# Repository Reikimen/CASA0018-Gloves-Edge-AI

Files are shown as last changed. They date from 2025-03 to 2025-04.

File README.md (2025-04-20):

---
typora-root-url: ./
---

# CASA0018-Gloves-Edge-AI

# Sign Language Recognition Glove

This project implements a wearable device that translates sign language gestures into text using flex sensors, an IMU, and edge ML inference.

## Project Overview

The Sign Language Recognition Glove aims to develop a wearable device that translates sign language by recognizing hand positions in real-time. This device uses flex sensors to detect finger bending and an IMU to capture hand orientation, enabling it to recognize specific sign language gestures. The system processes this data using a machine learning model deployed directly on an Arduino microcontroller, providing immediate feedback through an LCD display.

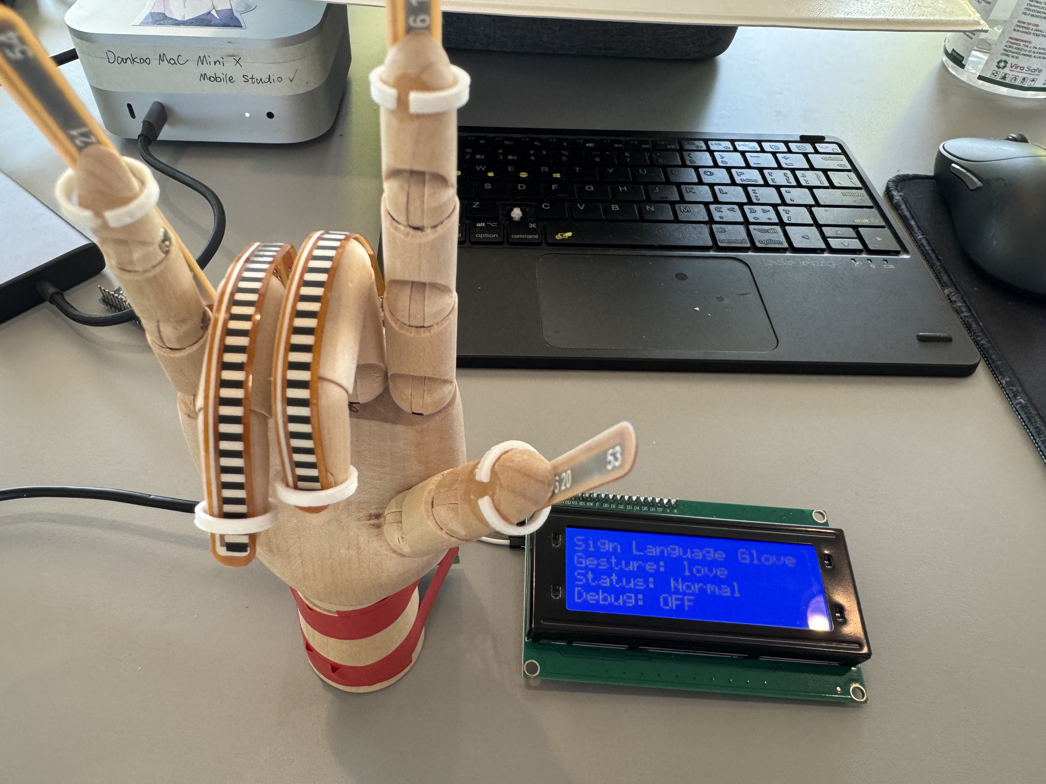
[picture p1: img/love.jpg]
love


### Features

- Real-time recognition of 6 sign language gestures (one, two, three, four, five, love)
- LCD display for visual feedback and status information
- Serial command interface with rich debugging features
- Statistical feature extraction for robust gesture recognition
- Low-latency processing suitable for real-time interaction

## Hardware Requirements

- Arduino Nano 33 BLE
- 5× Flex sensors (one for each finger)
- LCD2004 I2C display (address 0x27 by default)
- Breadboard/PCB for circuit connections
- Glove for mounting sensors

## Software Dependencies

- Arduino IDE
- [Arduino_LSM9DS1 library](https://www.arduino.cc/en/Reference/ArduinoLSM9DS1)
- [LiquidCrystal_I2C library](https://github.com/johnrickman/LiquidCrystal_I2C)
- Edge Impulse exported model library for Sign Language Recognition

## Installation

1. Clone this repository:

   ```
   git clone https://github.com/Reikimen/CASA0018-Gloves-Edge-AI.git
   ```

2. Open the Arduino sketch (`Sign_Language_Recognition_Split_EN_v0.2.ino`) in the Arduino IDE.

3. Install the required libraries through the Arduino Library Manager:

   - Arduino_LSM9DS1
   - LiquidCrystal_I2C

4. Export the machine learning model from Edge Impulse as an Arduino library.

   - Follow the [Edge Impulse documentation](https://docs.edgeimpulse.com/docs/deployment/arduino-library) for exporting the model
   - Add the exported library to your Arduino libraries folder

5. Connect the hardware components according to the pin definitions in `config.h`.

6. Upload the sketch to your Arduino Nano 33 BLE.

## Usage

Once the system is powered on and initialized:

1. The LCD will display the welcome message and initial sensor status.
2. Make a sign language gesture with the glove.
3. The system will recognize the gesture and display it on the LCD.
4. The built-in LED will flash to indicate successful recognition.

### Serial Commands

Connect to the serial monitor (115200 baud) to access these commands:

- `info` - Display current sensor data
- `raw` - Display raw ADC values
- `list` - Display list of supported gestures
- `finger` - Display finger bend angle visualization
- `features` - Display statistical features used by the model
- `debug` - Toggle debug mode
- `lcd` - Toggle LCD backlight
- `help` - Display this help message

## System Architecture

The system is organized into several modular components (`Sign_Language_Recognition_Split_EN_v0.2`):

- **config.h** - Configuration parameters, pin definitions, and calibration values
- **sensors.h** - Sensor data acquisition and processing
- **gestures.h** - Gesture recognition and inference
- **lcd_ui.h** - LCD display interface
- **ui.h** - User interface and command processing
- **Sign_Language_Recognition_Split_EN_v0.2.ino** - Main program

### Data Processing Pipeline

1. Flex sensors read finger bending angles and IMU reads hand orientation
2. Raw data is filtered and normalized
3. Statistical features are extracted from a sliding window of samples
4. The machine learning model performs inference on the features
5. Recognition results are displayed on LCD and via serial output

## Model Training

The model was trained using Edge Impulse with the following workflow:

1. Data collection using the same hardware setup

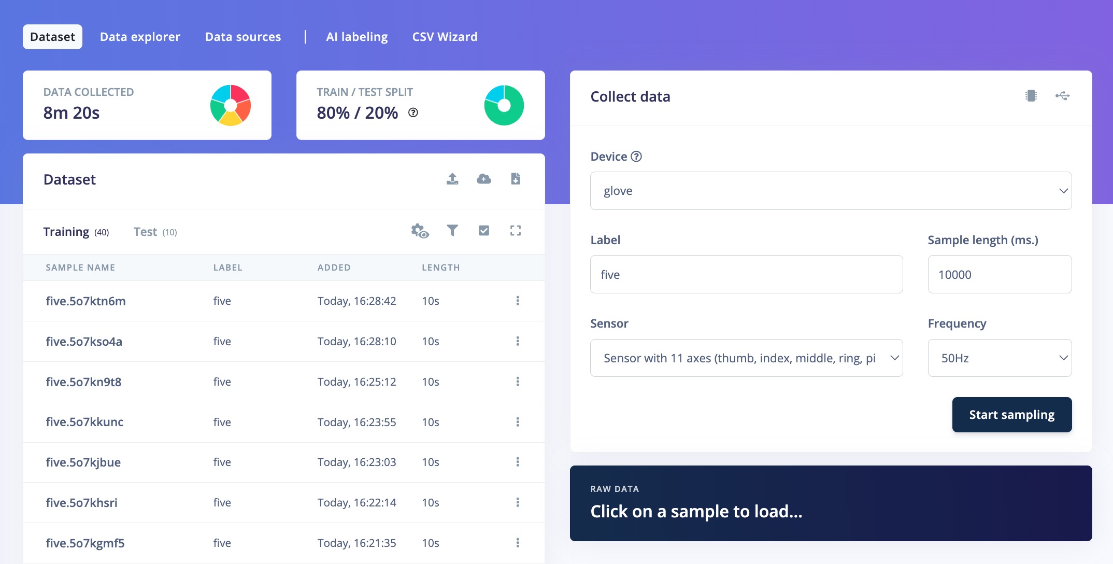
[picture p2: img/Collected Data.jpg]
Collected Data
   

2. Feature extraction: 7 statistical features (mean, min, max, RMS, StdDev, skewness, kurtosis) for each sensor

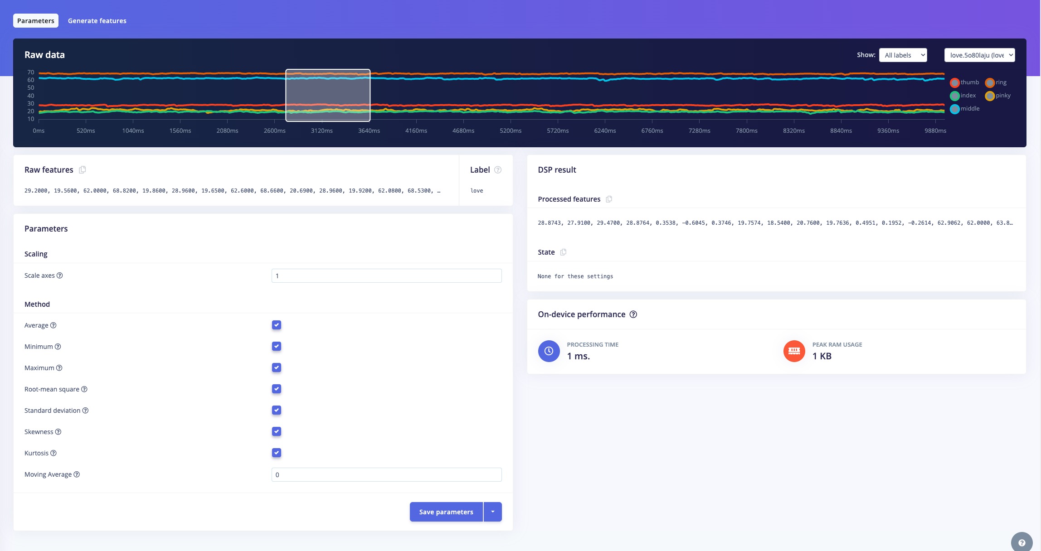
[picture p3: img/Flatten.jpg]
Flatten
   

3. Neural network training with several dense layers

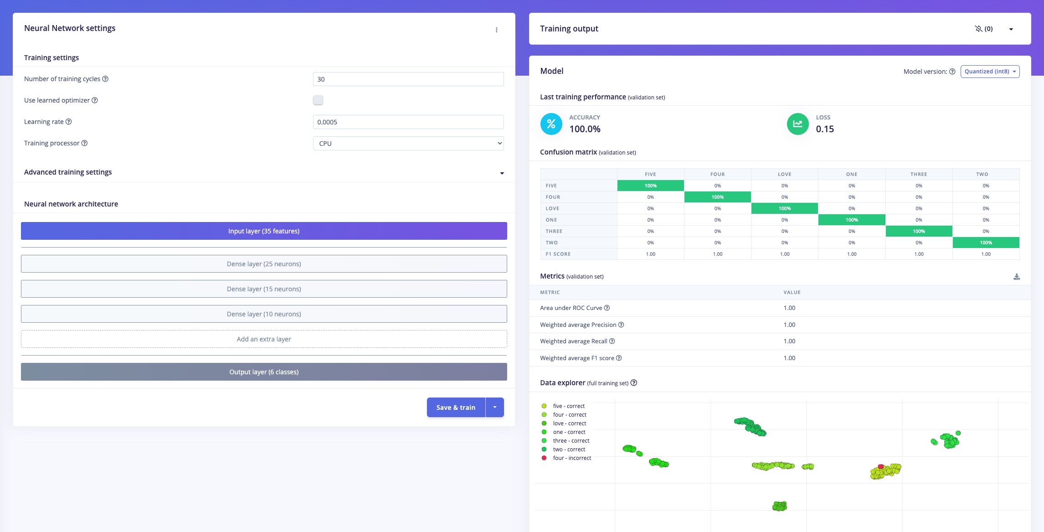
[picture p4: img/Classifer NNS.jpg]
Classifer NNS
   

4. Model optimization

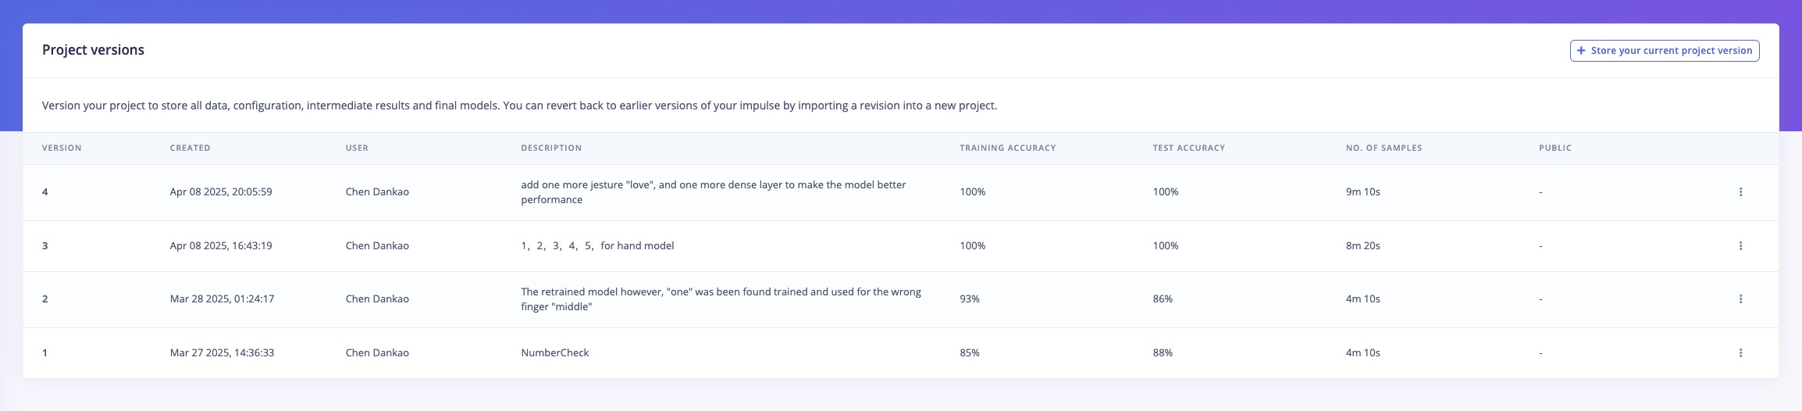
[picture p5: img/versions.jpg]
versions
   

5. Quantization to reduce model size and improve inference speed

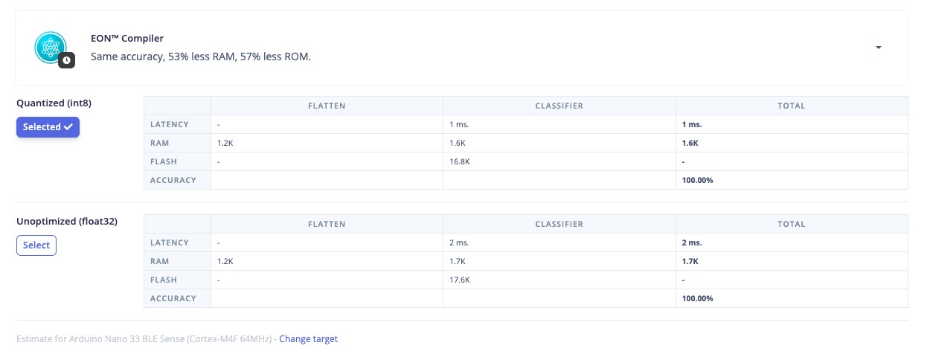
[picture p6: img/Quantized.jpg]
Quantized
   

## Calibration

The system uses calibration values for flex sensors defined in `config.h`:

```cpp
const int FLEX_STRAIGHT_ADC[5] = {
  FLEX_THUMB_STRAIGHT_ADC, 
  FLEX_INDEX_STRAIGHT_ADC, 
  FLEX_MIDDLE_STRAIGHT_ADC, 
  FLEX_RING_STRAIGHT_ADC, 
  FLEX_PINKY_STRAIGHT_ADC
};

const int FLEX_BENT_ADC[5] = {
  FLEX_THUMB_BENT_ADC, 
  FLEX_INDEX_BENT_ADC, 
  FLEX_MIDDLE_BENT_ADC, 
  FLEX_RING_BENT_ADC, 
  FLEX_PINKY_BENT_ADC
};
```

If needed, update these values based on your specific sensor characteristics. (Use the calabration programe)

## Performance

The system:

- Samples sensor data at 50Hz
- Performs inference every 300ms
- Updates LCD every 200ms
- Uses a confidence threshold of 0.60 for gesture detection
- Implements stability detection to prevent jitter in recognition results

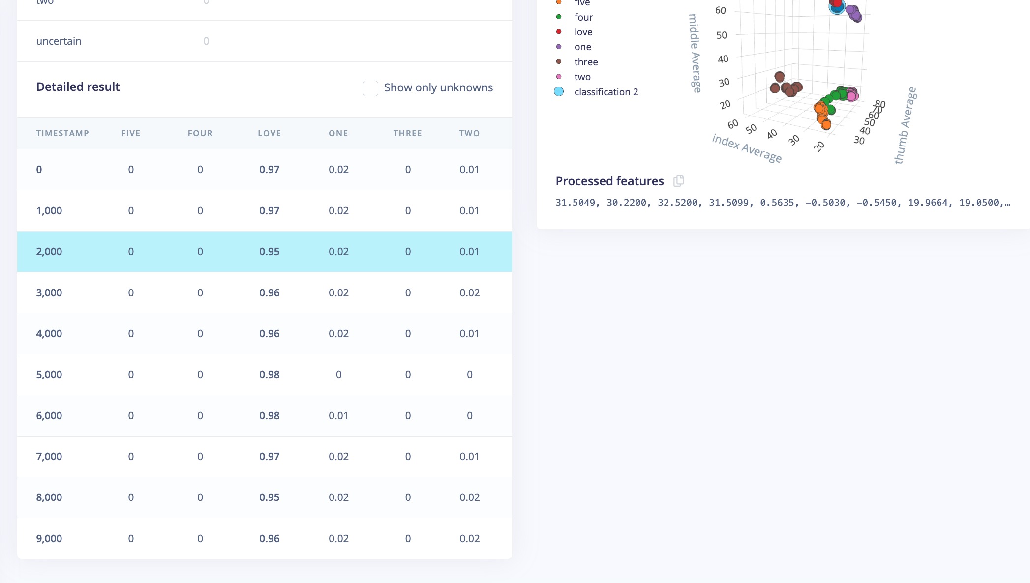
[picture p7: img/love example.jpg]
love example


## Troubleshooting

- If the LCD doesn't display anything, check the I2C address (default is 0x27)
- If gestures aren't recognized correctly, consider recalibrating the flex sensors
- Ensure the flex sensors are properly positioned on each finger
- Check serial output for debugging information when issues occur

## Future Improvements

- Add support for more sign language gestures
- Implement adaptive calibration to handle different users
- Add Bluetooth communication for mobile app integration
- Support for dynamic gestures (not just static positions)
- Improve model architecture for better accuracy with less computation

## Acknowledgments

- UCL Centre for Advanced Spatial Analysis (CASA)
- Edge Impulse for the embedded machine learning platform
- Arduino community for libraries and support

## Author

Dankao Chen - [GitHub](https://github.com/Reikimen)

------

Project created as part of the CASA0018 - Deep Learning for Sensor Networks course at University College London.

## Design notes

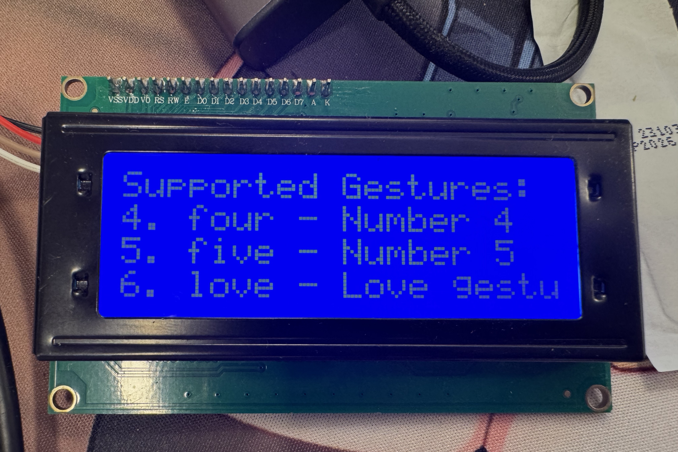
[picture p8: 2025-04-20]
img/LCD.jpg

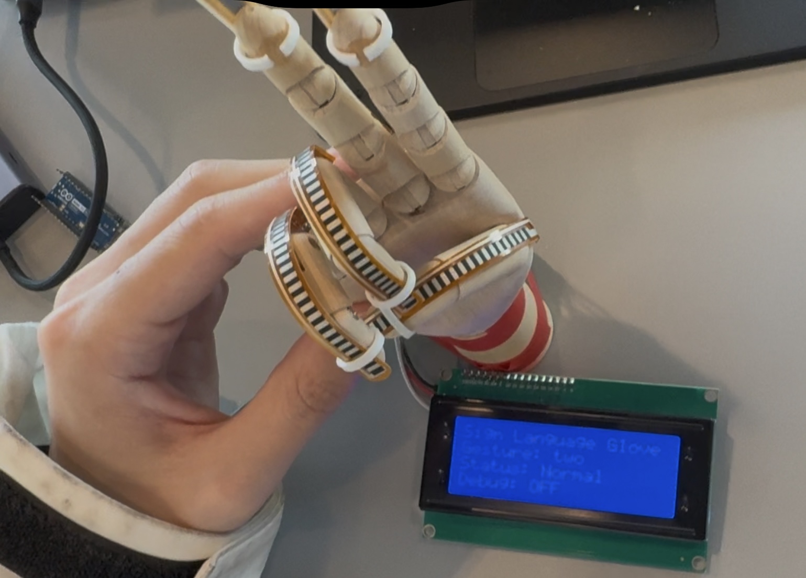
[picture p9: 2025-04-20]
img/two.jpg

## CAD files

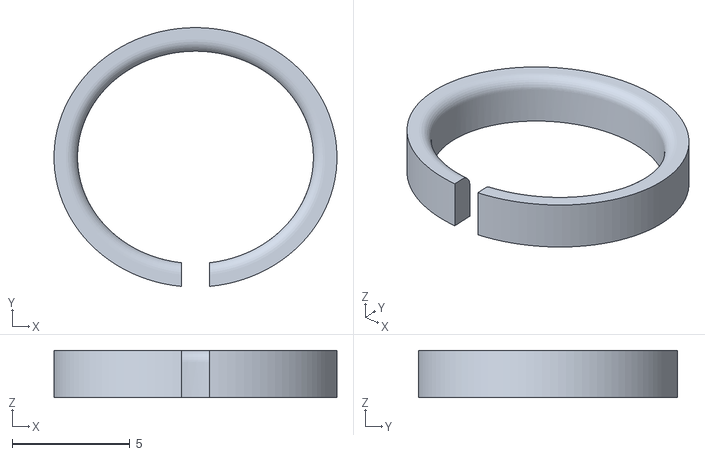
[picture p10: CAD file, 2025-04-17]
glove-ring v2.stl
12.0 x 11.0 x 2.00

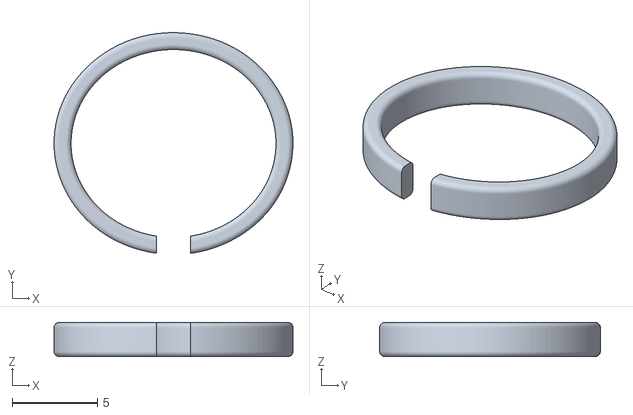
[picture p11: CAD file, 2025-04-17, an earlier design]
glove-ring v1.stl
14.0 x 12.9 x 2.00

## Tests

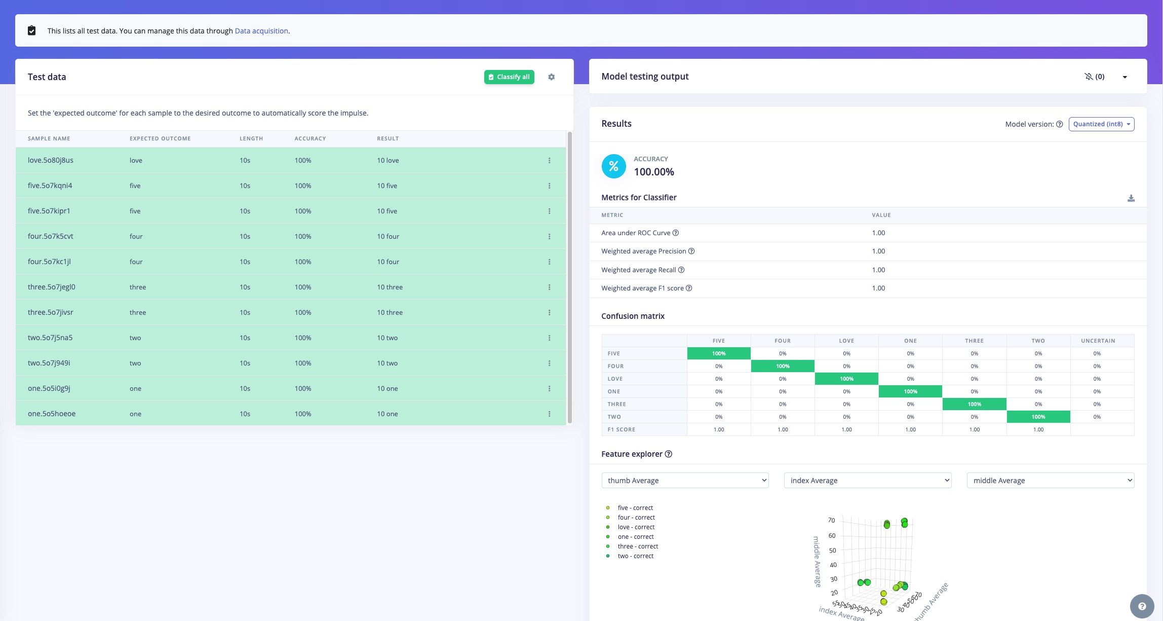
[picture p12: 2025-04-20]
img/Test Data.jpg

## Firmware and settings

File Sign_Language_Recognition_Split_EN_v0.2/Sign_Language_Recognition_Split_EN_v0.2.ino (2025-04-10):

/*
 * Sign Language Glove - Gesture Recognition Program with LCD Support
 * 
 * Features:
 * 1. Reads flex sensor data using calibrated ADC values
 * 2. Calculates statistical features (average, min, max, RMS, stddev, skew, kurtosis)
 * 3. Uses Edge Impulse exported model to recognize digital and special gestures
 * 4. Displays recognition results on serial monitor and LCD2004 display
 * 
 * Usage:
 * 1. Export Arduino library from Edge Impulse and add it to the project
 * 2. Ensure Sign-Language-Glove_inferencing.h is included in the project
 * 3. Place all header files (.h) and main program in the same directory
 * 4. Upload code to Arduino Nano 33 BLE
 * 5. Connect LCD2004 I2C display (default address 0x27)
 * 6. Open serial monitor (115200 baud rate) to view recognition results
 */

#include <Arduino_LSM9DS1.h>
#include <Sign-Language-Glove_inferencing.h>
#include "config.h"
#include "sensors.h"
#include "gestures.h"
#include "ui.h"
#ifdef USE_LCD
#include "lcd_ui.h"
#endif

// Time tracking
unsigned long lastInferenceTime = 0;
unsigned long lastSampleTime = 0;
unsigned long lastLcdUpdateTime = 0;

void setup() {
  // Initialize serial communication
  Serial.begin(115200);
  delay(3000); // Wait for serial connection
  
  // Initialize LED
  pinMode(LED_BUILTIN, OUTPUT);
  
  #ifdef USE_LCD
  // Initialize LCD
  initLCD();
  #endif
  
  // Initialize sensors
  if (!initSensors()) {
    Serial.println("Sensor initialization failed!");
    #ifdef USE_LCD
    showTempMessage("ERROR:", "Sensor initialization", "failed!", "", 0);
    #endif
    while (1) {
      digitalWrite(LED_BUILTIN, HIGH);
      delay(100);
      digitalWrite(LED_BUILTIN, LOW);
      delay(100);
    }
  }
  
  // Display welcome message
  showWelcomeMessage();
  
  // Fill initial data windows
  Serial.println("Initializing data window with initial samples...");
  #ifdef USE_LCD
  showTempMessage("Initializing...", "Collecting data", "samples for window", "", 1000);
  #endif
  
  for (int i = 0; i < WINDOW_SIZE; i++) {
    readAllSensors();
    updateDataWindow();
    delay(10);
  }
  Serial.println("Data window initialization complete.");
  
  // Short LED flash to indicate initialization complete
  for (int i = 0; i < 3; i++) {
    digitalWrite(LED_BUILTIN, HIGH);
    delay(100);
    digitalWrite(LED_BUILTIN, LOW);
    delay(100);
  }
}

void loop() {
  // Current time
  unsigned long currentMillis = millis();
  
  // Sample data at fixed intervals
  if (currentMillis - lastSampleTime >= SAMPLING_INTERVAL_MS) {
    lastSampleTime = currentMillis;
    
    // Read all sensor data
    readAllSensors();
    
    // Update the data window with new readings
    updateDataWindow();
  }
  
  // Periodically perform inference
  if (currentMillis - lastInferenceTime >= INFERENCE_INTERVAL_MS) {
    lastInferenceTime = currentMillis;
    
    // Prepare statistical features for the model
    prepareFeatures();
    
    // Only run inference if we have a full data window
    if (windowFilled) {
      // Run inference and process results
      runInference();
      
      #ifdef USE_LCD
      // Update LCD with current gesture information
      if (currentMillis - lastLcdUpdateTime >= LCD_UPDATE_INTERVAL_MS) {
        lastLcdUpdateTime = currentMillis;
        updateLCD(lastRecognizedGesture.c_str());
      }
      #endif
    }
  }
  
  // Process commands from serial
  if (Serial.available()) {
    String command = Serial.readStringUntil('\n');
    command.trim();
    handleCommand(command);
  }
}

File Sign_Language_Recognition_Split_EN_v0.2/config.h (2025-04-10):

/*
 * config.h - Sign Language Glove Project Configuration
 * 
 * Contains all hardware definitions, calibration values and parameter configurations
 */

#ifndef CONFIG_H
#define CONFIG_H

// LCD Support - comment out this line to disable LCD functionality
#define USE_LCD

// Flex sensor pin definitions
#define FLEX_PIN_THUMB A0
#define FLEX_PIN_INDEX A1
#define FLEX_PIN_MIDDLE A2
#define FLEX_PIN_RING A3
#define FLEX_PIN_PINKY A6

// Flex sensor calibration values - as obtained from the calibration program
const int FLEX_THUMB_STRAIGHT_ADC = 330;    // ADC value when straight
const int FLEX_INDEX_STRAIGHT_ADC = 440;    // ADC value when straight
const int FLEX_MIDDLE_STRAIGHT_ADC = 400;   // ADC value when straight
const int FLEX_RING_STRAIGHT_ADC = 430;     // ADC value when straight
const int FLEX_PINKY_STRAIGHT_ADC = 390;    // ADC value when straight

const int FLEX_THUMB_BENT_ADC = 220;    // ADC value when fully bent - ADC decreases when bent
const int FLEX_INDEX_BENT_ADC = 360;    // ADC value when fully bent - ADC decreases when bent
const int FLEX_MIDDLE_BENT_ADC = 320;   // ADC value when fully bent - ADC decreases when bent
const int FLEX_RING_BENT_ADC = 335;     // ADC value when fully bent - ADC decreases when bent
const int FLEX_PINKY_BENT_ADC = 320;    // ADC value when fully bent - ADC decreases when bent

// Integrated into arrays for easier processing
const int FLEX_STRAIGHT_ADC[5] = {
  FLEX_THUMB_STRAIGHT_ADC, 
  FLEX_INDEX_STRAIGHT_ADC, 
  FLEX_MIDDLE_STRAIGHT_ADC, 
  FLEX_RING_STRAIGHT_ADC, 
  FLEX_PINKY_STRAIGHT_ADC
};

const int FLEX_BENT_ADC[5] = {
  FLEX_THUMB_BENT_ADC, 
  FLEX_INDEX_BENT_ADC, 
  FLEX_MIDDLE_BENT_ADC, 
  FLEX_RING_BENT_ADC, 
  FLEX_PINKY_BENT_ADC
};

// LCD Update interval
#define LCD_UPDATE_INTERVAL_MS 200  // Update LCD every 200ms

// Data processing parameters
#define WINDOW_SIZE 50          // Number of samples to collect for statistics
#define FEATURE_COUNT 35        // Total features (5 sensors × 7 statistics)
#define STATS_PER_SENSOR 7      // Number of statistics per sensor

// Sampling and inference configuration
#define SAMPLING_INTERVAL_MS 20 // 50Hz sampling rate
#define INFERENCE_INTERVAL_MS 300  // Perform inference every 300ms
#define CONFIDENCE_THRESHOLD 0.60 // Confidence threshold (0.0-1.0)

// Filtering parameters
#define ALPHA 0.3  // Low-pass filter coefficient

// Gesture labels and descriptions
const char* GESTURE_LABELS[] = {"one", "two", "three", "four", "five", "love"};
const char* GESTURE_DESCRIPTIONS[] = {
  "Number 1 (Index finger extended)",
  "Number 2 (Index and middle fingers extended)",
  "Number 3 (Thumb, index and middle fingers extended)",
  "Number 4 (Four fingers extended, thumb tucked)",
  "Number 5 (All five fingers extended)",
  "Love gesture (Thumb and pinky extended, forming heart shape)"
};

#endif // CONFIG_H

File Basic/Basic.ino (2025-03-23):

/*
 * 手语翻译手套 - 基础验证阶段代码
 * 
 * 功能:
 * 1. 读取Arduino Nano 33 BLE内置IMU (LSM9DS1)数据
 * 2. 读取连接到模拟引脚的5个弯曲传感器数据
 * 3. 通过串口监视器显示所有传感器数据
 * 4. 基本数据滤波和校准
 * 
 * 硬件连接:
 * - 弯曲传感器1: A0 (拇指)
 * - 弯曲传感器2: A1 (食指)
 * - 弯曲传感器3: A2 (中指)
 * - 弯曲传感器4: A3 (无名指)
 * - 弯曲传感器5: A4 (小指)
 * - IMU: 内置在Nano 33 BLE板上
 * 
 * 注意: 弯曲传感器需要配合10K电阻作为分压电路使用
 */

#include <Arduino_LSM9DS1.h>

// 弯曲传感器引脚定义
#define FLEX_PIN_THUMB A0
#define FLEX_PIN_INDEX A1
#define FLEX_PIN_MIDDLE A2
#define FLEX_PIN_RING A3
#define FLEX_PIN_PINKY A4

// 弯曲传感器校准值
// 这些值需要根据您的传感器实际测量调整
const float FLEX_STRAIGHT_RESISTANCE = 10000.0; // 10K欧姆 - 平直时
const float FLEX_BENT_RESISTANCE = 40000.0;     // 40K欧姆 - 弯曲时
const float VCC = 3.3;                          // 供电电压
const float R_DIV = 10000.0;                    // 分压电阻值

// 滤波参数
const float ALPHA = 0.3; // 低通滤波系数 (0-1)

// 存储滤波后的传感器值
float filteredFlexValues[5] = {0};

// IMU数据滤波值
float filteredAx = 0, filteredAy = 0, filteredAz = 0;
float filteredGx = 0, filteredGy = 0, filteredGz = 0;

// 弯曲度计算函数
float calculateBendPercentage(int adcValue, float straightResistance, float bentResistance) {
  // 将ADC值转换为电阻值
  float Vflex = adcValue * VCC / 1023.0;
  float Rflex = R_DIV * (VCC / Vflex - 1.0);
  
  // 计算弯曲百分比 (0% = 直, 100% = 完全弯曲)
  float bendPercentage = map(Rflex, straightResistance, bentResistance, 0, 100);
  
  // 限制在0-100范围内
  if (bendPercentage < 0) bendPercentage = 0;
  if (bendPercentage > 100) bendPercentage = 100;
  
  return bendPercentage;
}

// 低通滤波函数
float lowPassFilter(float currentValue, float previousFilteredValue, float alpha) {
  return previousFilteredValue + alpha * (currentValue - previousFilteredValue);
}

void setup() {
  // 初始化串口通信
  Serial.begin(115200);
  while (!Serial);  // 等待串口连接
  
  Serial.println("手语翻译手套 - 基础传感器测试");
  
  // 初始化IMU
  if (!IMU.begin()) {
    Serial.println("IMU初始化失败!");
    while (1);
  }
  
  // 设置IMU采样率和量程
  // 加速度计量程为±4g，陀螺仪量程为±500dps
  Serial.println("IMU初始化成功");
  
  // 显示传感器详细信息
  Serial.print("加速度计采样率 = ");
  Serial.print(IMU.accelerationSampleRate());
  Serial.println(" Hz");
  Serial.print("陀螺仪采样率 = ");
  Serial.print(IMU.gyroscopeSampleRate());
  Serial.println(" Hz");
  
  Serial.println("校准中...");
  // 简单校准过程 - 保持手套平放3秒
  for (int i = 0; i < 50; i++) {
    // 读取弯曲传感器作为基准值
    // 这里可以添加更复杂的校准逻辑
    delay(60);
  }
  
  Serial.println("校准完成，开始数据读取");
  Serial.println("===========================================");
  Serial.println("   拇指  食指  中指  无名  小指   Ax   Ay   Az   Gx   Gy   Gz");
  Serial.println("===========================================");
}

void loop() {
  // 存储传感器原始读数
  int flexValues[5];
  float ax, ay, az;  // 加速度计数据 (g)
  float gx, gy, gz;  // 陀螺仪数据 (度/秒)
  
  // 读取所有弯曲传感器值
  flexValues[0] = analogRead(FLEX_PIN_THUMB);
  flexValues[1] = analogRead(FLEX_PIN_INDEX);
  flexValues[2] = analogRead(FLEX_PIN_MIDDLE);
  flexValues[3] = analogRead(FLEX_PIN_RING);
  flexValues[4] = analogRead(FLEX_PIN_PINKY);
  
  // 读取IMU数据
  if (IMU.accelerationAvailable() && IMU.gyroscopeAvailable()) {
    IMU.readAcceleration(ax, ay, az);
    IMU.readGyroscope(gx, gy, gz);
    
    // 对IMU数据进行滤波
    filteredAx = lowPassFilter(ax, filteredAx, ALPHA);
    filteredAy = lowPassFilter(ay, filteredAy, ALPHA);
    filteredAz = lowPassFilter(az, filteredAz, ALPHA);
    filteredGx = lowPassFilter(gx, filteredGx, ALPHA);
    filteredGy = lowPassFilter(gy, filteredGy, ALPHA);
    filteredGz = lowPassFilter(gz, filteredGz, ALPHA);
  }
  
  // 计算弯曲百分比并应用滤波
  for (int i = 0; i < 5; i++) {
    float bendPercentage = calculateBendPercentage(
      flexValues[i], 
      FLEX_STRAIGHT_RESISTANCE, 
      FLEX_BENT_RESISTANCE
    );
    
    // 应用低通滤波
    filteredFlexValues[i] = lowPassFilter(bendPercentage, filteredFlexValues[i], ALPHA);
  }
  
  // 格式化并打印数据
  char buffer[120];
  sprintf(buffer, "%5.1f %5.1f %5.1f %5.1f %5.1f %5.2f %5.2f %5.2f %5.1f %5.1f %5.1f",
          filteredFlexValues[0], filteredFlexValues[1], filteredFlexValues[2], 
          filteredFlexValues[3], filteredFlexValues[4],
          filteredAx, filteredAy, filteredAz, 
          filteredGx, filteredGy, filteredGz);
  Serial.println(buffer);
  
  // 添加可视化指示 (当弯曲度超过50%时显示*)
  Serial.print("状态: ");
  for (int i = 0; i < 5; i++) {
    if (filteredFlexValues[i] > 50) {
      Serial.print("* ");
    } else {
      Serial.print("- ");
    }
  }
  Serial.println();
  
  // 短暂延时
  delay(100);  // 10Hz更新频率
}
